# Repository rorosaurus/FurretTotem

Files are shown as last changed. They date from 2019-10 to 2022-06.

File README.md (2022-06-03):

## Wait but how?
* The LED panels are driven by an ESP32, controlled by a phone via Wifi!
* Yes, he's built using "Arduino"! No, they aren't normal "Neopixel" LEDs, they're HUB75!  Yes, he is adorable!
* The LED panels were $25 each and the microcontroller was $5. It's powered by a normal USB battery pack!
* The original pixel art animation was done by the extremely talented [Alex Illustration](https://www.artstation.com/alexillustration)! We used Photoshop to modify the original animation and to make all the other animations!

## Where is Furret?
Furret uses [Meshtastic](https://meshtastic.org/), a peer-to-peer LoRa mesh network, for long range (up to 10km!) reliable texting and GPS coordinate sharing! After getting your hardware (~$30) and setting up the device, join his channel and you can find Furret easily at festivals! We'll try to announce future planned events on Instagram!

[Click here to join his channel](https://www.meshtastic.org/d/#CjAYAyIgmvE-KciSpfpBhmnGTf2xxqEcX0OudQ_G3KwMii1EzjIqClJhdmVGdXJyZXQ), or scan the QR code below!

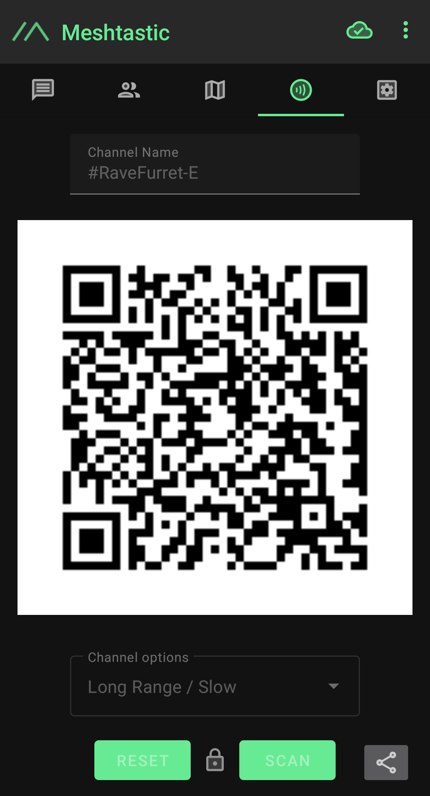
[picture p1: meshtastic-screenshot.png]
Furret's Meshtastic Channel


## Special Thanks
* [@alex_illustrat](https://twitter.com/alex_illustrat) - who [originally created the 8bit pixel art for Furret Walking](https://www.youtube.com/watch?v=ylnLUMmBNKc). See more of his work on [ArtStation](https://alexillustration.artstation.com/)!
* [narpy](https://www.youtube.com/channel/UCKYFHftFxQOJghmrEaK32sg) - for [starting the most adorable, wholesome, meme](https://www.youtube.com/watch?v=JVHybsJbTFY)
* [@pikachutotem](https://www.instagram.com/pikachutotem/) - who inspired me to make Furret!
* Sprite_tm, Craig A. Lindley, Louis Beaudoin, and Marc Merlin - for the below libraries and helpful forum posts :)
* [bigclive](https://www.youtube.com/channel/UCtM5z2gkrGRuWd0JQMx76qA) for showing me the [perfect bubble blowing mechanism](https://www.youtube.com/watch?v=BvQtl3ciGcA)!

## Code
This repository isn't meant to be a good sample project, it's just my personal project. It was built on top of so many incredible libraries:
* [Arduino core for the ESP32](https://github.com/espressif/arduino-esp32)
* [SmartMatrix Library for ESP32](https://github.com/pixelmatix/SmartMatrix/tree/teensylc)
  * I did a [dirty hack](https://github.com/rorosaurus/SmartMatrix/commit/c46fe8d7be686caaaa3b7198bc4b7b24c6114df8) to free up some DMA memory to enable Wifi for this project.
* [Animated GIFs on ESP32](https://github.com/marcmerlin/AnimatedGIFs)
* [Arduino plugin for uploading files to ESP32 file system](https://github.com/me-no-dev/arduino-esp32fs-plugin)

## Hardware
* [PCB I designed](https://github.com/rorosaurus/esp32-hub75-driver) to drive HUB75 panels with an ESP32: [Buy on Tindie!](https://www.tindie.com/products/18357/)
  * This part is optional, but *greatly* simplifies your wiring!
* ESP32-DEVKIT-V1: [Amazon ($14 for 2)](https://smile.amazon.com/gp/product/B07Q576VWZ/)
  * You can use a different ESP32 if you don't use my PCB. Just remember to verify it has the required pins mentioned below!
* 128x64px, P2.5, 1/32, HUB75E purchased on [AliExpress](https://www.aliexpress.com/item/32972741517.html?spm=a2g0s.12269583.0.0.48e74198VArDtK)
* Bubble machine extracted from children's bubble wand toy, purchased on [eBay](https://www.ebay.com/itm/332880742452)
* Some PVC pipe and a tripod!
* Furret's powered by a 100Wh USB battery bank! At full brightness, one panel can pull about 2 Amps @ 5 Volts. Since the LED panel power requirements can spike depending on the animation, I recommend running the ESP32 from a separate 5V power source to avoid brownouts due to voltage sag.

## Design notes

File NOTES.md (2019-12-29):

## Power Notes

Powering both panels off one 5V/3A USB port, I can reach about 150/255 before nearing 3A. Some animations with more white pixels would breach 3A and significantly reduce voltage (below 4V).

It's best to power the ESP32 (~1.5W constant) separately, so that voltage sag from the panels does not cause brownouts.

For sunlight conditions, the ability to go brighter would be better.  Maybe use 2 ports and split up the power distribution for each panel?

**Actual power measurements:**
* ESP32 running basic-walk.gif: `1W`
* ESP32 with Wifi ON running basic-walk.gif: `1.5W`
* Bubble machine running @ 5V: `1.5-4W`
* 1x LED panel running basic-walk.gif:

Brightness | Power
-----------|------
10/255 | ~1.5W
25/255 | ~2W
50/255 | 3W
128/255 | 5.7W
165/255 | 6.8W
200/255 | 8.3W
255/255 | 10W

## Checking DMA-capable memory free
````
Serial.print("8-bit/DMA Memory Available: ");
Serial.println(heap_caps_get_free_size(MALLOC_CAP_DMA));
````

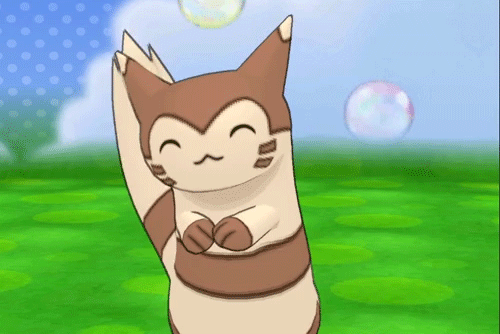
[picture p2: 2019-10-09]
head-bob-loop.gif

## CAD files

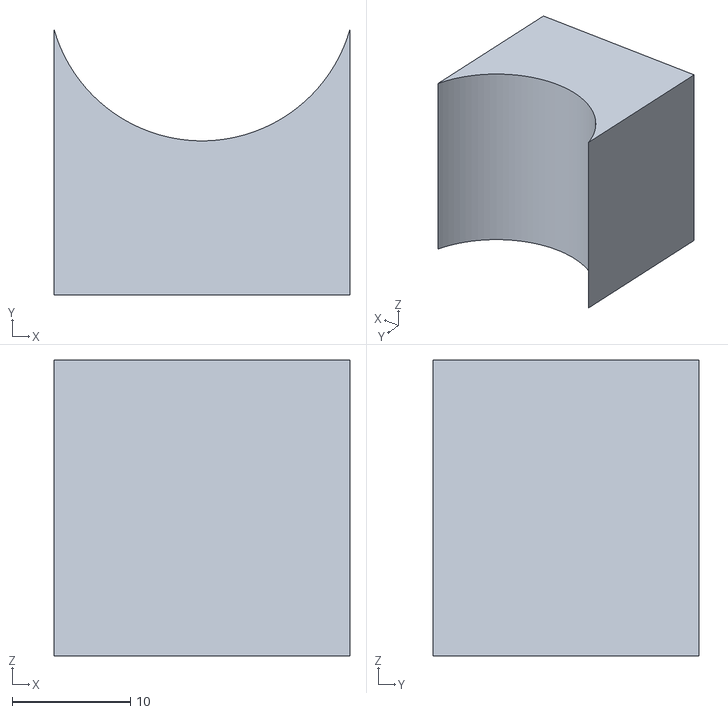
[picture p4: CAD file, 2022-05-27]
hardware/prisim-light/light-mount v0.stl
25.0 x 22.4 x 25.0

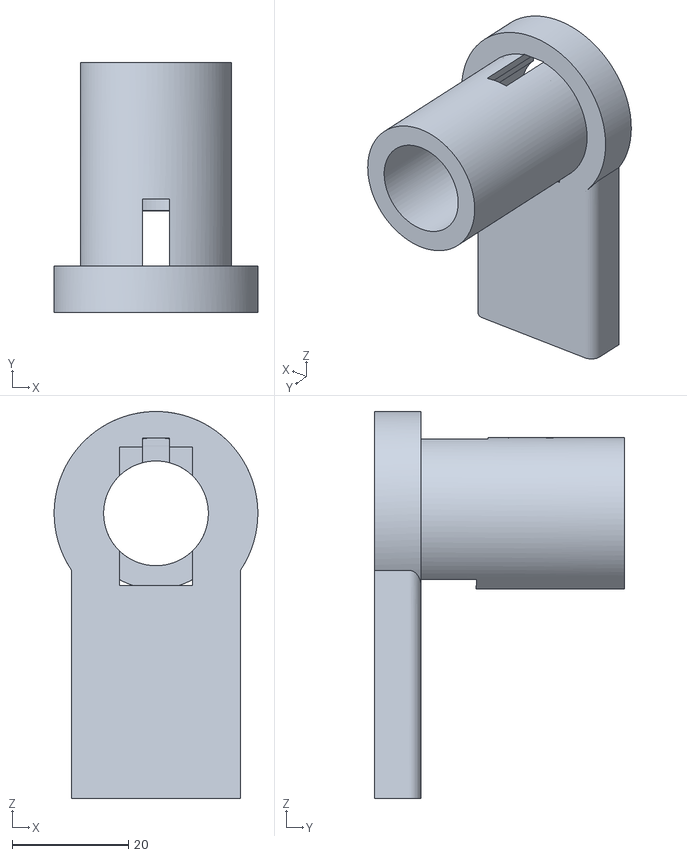
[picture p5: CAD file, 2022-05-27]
hardware/prisim-light/FS90R-mount v16.stl
35.0 x 43.0 x 66.5

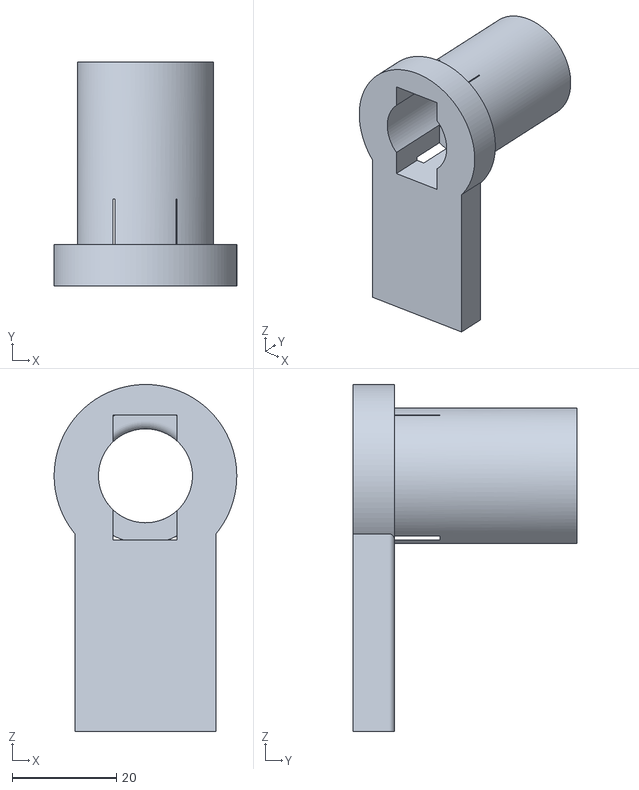
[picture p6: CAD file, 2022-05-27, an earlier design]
hardware/prisim-light/FS90R-mount v6.stl
35.0 x 43.0 x 66.5

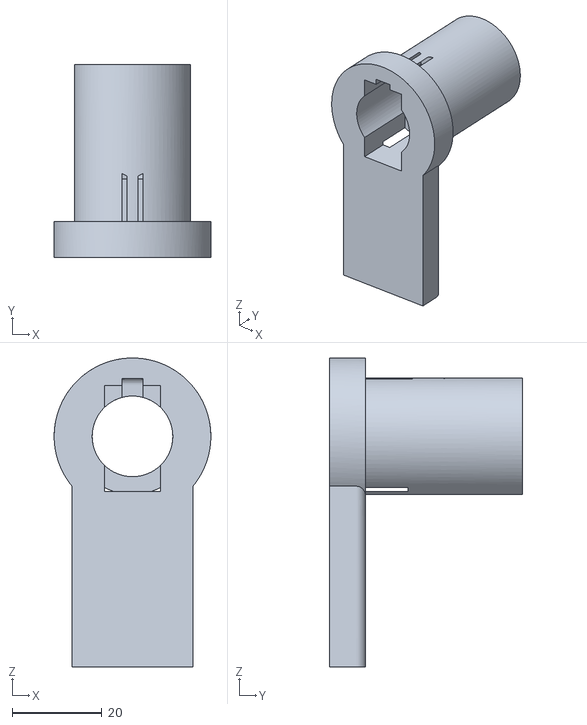
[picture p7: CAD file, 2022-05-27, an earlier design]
hardware/prisim-light/FS90R-mount v14.stl
35.0 x 43.0 x 69.0

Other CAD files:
hardware/prisim-light/FS90R-mount v15.stl
hardware/prisim-light/FS90R-mount v3.stl
hardware/prisim-light/FS90R-mount v9.stl
hardware/prisim-light/FS90R-mount v10.stl
hardware/prisim-light/FS90R.f3d

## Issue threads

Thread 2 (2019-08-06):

consider FatFS instead of SPIFFS

marcmerlin, 2019-08-06:
As you add more data to SPIFFS, you'll notice that the reads slowdown to a point that your animation is not nice anymore.
Fix for this is switching to FatFS:
http://marc.merlins.org/perso/arduino/post_2019-03-30_Using-FatFS-FFat-on-ESP32-Flash-With-Arduino.html

rorosaurus, 2019-10-01:
Thanks Marc!  I will definitely plan on migrating to that as I expand this project! :)

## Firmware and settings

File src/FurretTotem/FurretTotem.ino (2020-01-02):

/*
 * HE WALK!
 */

#define DISABLE_MATRIX_TEST
#define NEOMATRIX

#define defaultBrightness 50 // 25 is good for home testing, 50 is a good default for shows
#define minBrightness 0
#define maxBrightness 150 // 165 is roughly equivalent to 3A with 2 displays, but leave some headroom

#include <DNSServer.h>
#include <WiFi.h>
#include <AsyncTCP.h>
#include "ESPAsyncWebServer.h"
#include "secrets.h"
#include "GifAnim_Impl.h"

int currentBrightness = defaultBrightness;
bool nextFlag = false;
bool prevFlag = false;
int newIndex = -1;
int currentIndex = FIRSTINDEX;

// If the matrix is a different size than the GIFs, allow panning through the GIF
int OFFSETX = 0;
int OFFSETY = 0;
int FACTX = 0;
int FACTY = 0;

int num_files;
String filenameOptions = "";

//DNSServer dnsServer;
AsyncWebServer server(80);

String processor(const String& var){
  if(var == "MIN_BRIGHTNESS") return String(minBrightness);
  if(var == "MAX_BRIGHTNESS") return String(maxBrightness);
  if(var == "CURRENT_BRIGHTNESS") return String(currentBrightness);
  if(var == "CURRENT_INDEX") return String(currentIndex);
  if(var == "LIST_FILENAME_OPTIONS") return filenameOptions;
  return String();
}

class CaptiveRequestHandler : public AsyncWebHandler {
public:
  CaptiveRequestHandler() {}
  virtual ~CaptiveRequestHandler() {}

  bool canHandle(AsyncWebServerRequest *request){
    //request->addInterestingHeader("ANY");
    return true;
  }

  void handleRequest(AsyncWebServerRequest *request) {
    // handle other file requests
    if (request->url() == "/styles.css"){
      request->send(SPIFFS, "/www/styles.css", "text/css");
    }
    else { // handle parameters
      if(request->hasParam("next")){
        Serial.println("NEXT pressed");
        nextFlag = true;
      }
      if(request->hasParam("prev")){
        Serial.println("PREVIOUS pressed");
        prevFlag = true;
      }
      if(request->hasParam("brightness")){
        AsyncWebParameter* p = request->getParam("brightness");
        currentBrightness = p->value().toInt();
        Serial.print("New brightness: ");
        Serial.println(currentBrightness);
      }
      if(request->hasParam("newFileIndex")){
        AsyncWebParameter* p = request->getParam("newFileIndex");
        newIndex = p->value().toInt();
        Serial.print("New file index: ");
        Serial.println(newIndex);
      }

      // catch everything else
      //Send index.htm with template processor function
      request->send(SPIFFS, "/www/index.htm", "text/html", false, processor);
    }
  }
};

// Setup method runs once, when the sketch starts
void setup() {
    Serial.begin(115200);
    
    Serial.println("Starting AnimatedGIFs Sketch");
    sav_setup();

    #if ENABLE_SCROLLING == 1
	  matrix.addLayer(&scrollingLayer); 
    #endif

    // Determine how many animated GIF files exist
    num_files = enumerateGIFFiles(GIF_DIRECTORY, true);

    if(num_files < 0) {
      #if ENABLE_SCROLLING == 1
      scrollingLayer.start("No gifs directory", -1);
      #endif
      die("No gifs directory");
    }

    if(!num_files) {
        #if ENABLE_SCROLLING == 1
        scrollingLayer.start("Empty gifs directory", -1);
        #endif
        die("Empty gifs directory");
    }
    
    Serial.print("Index of files: 0 to ");
    Serial.println(num_files);
    Serial.flush();
    
    // We didn't have enough DMA memory to use Wifi until I made this hack in SmartMatrix, effectively removing the double buffer:
    // https://github.com/rorosaurus/SmartMatrix/commit/c46fe8d7be686caaaa3b7198bc4b7b24c6114df8
    Serial.println("Configuring access point...");
    WiFi.softAP(ssid, password, 1, 1, 1); // channel 1 (default), hide SSID, max connected clients = 1
    
//    dnsServer.start(53, "*", WiFi.softAPIP());
    
    server.addHandler(new CaptiveRequestHandler());//only when requested from AP
    server.begin();
    Serial.print("Server started. IP Address: ");
    Serial.println(WiFi.softAPIP());
}

void adjust_gamma(float change) {
#ifdef NEOMATRIX
    matrix_gamma += change;
    matrix->precal_gamma(matrix_gamma);
    Serial.print("Change gamma to: "); 
    Serial.println(matrix_gamma); 
#else
    Serial.println("Gamma changing not supported in SmartMatrix lib"); 
#endif
}


void loop() {
//    dnsServer.processNextRequest();

    matrixLayer.setBrightness(currentBrightness);
    
    static unsigned long lastTime = millis();
    static int index = FIRSTINDEX;
    currentIndex = index;
    static int8_t new_file = 1;
    static uint16_t frame = 0;
    // allow stalling on a picture if requested
    static uint32_t longer = 0;
    char readchar;
    // frame by frame display
    static bool debugframe = false;
    bool gotnf = false;
    // clear display before each frame
    static bool clear = false;

  if (nextFlag){
    Serial.println("Wifi => next");
    new_file = 1;  
    index++;
    nextFlag = false;
  }
  
  if (prevFlag){
    Serial.println("Wifi => previous");
    new_file = 1;  
    index--;
    prevFlag = false;
  }
  if (newIndex != -1){
      new_file = 1;
      index = newIndex;
      newIndex = -1;
  }

    if (Serial.available()) readchar = Serial.read(); else readchar = 0;

    switch(readchar) {
    case 'n': 
	Serial.println("Serial => next"); 
	new_file = 1;  
	index++;
	break;

    case 'p':
	Serial.println("Serial => previous");
	new_file = 1;
	index--;
	break;

    case 'f':
	Serial.println("Serial => debug frames, press 'g' for next frame");
	debugframe = true;
	longer = 3600; //  if frame debugging, keep current gif for 1h
	break;

    case 'g':
	Serial.println("Serial => next frame");
	gotnf = true;
	break;

    case 'c':
	Serial.print("Toggle clear screen: ");
	clear = !clear;;
	Serial.println(clear);
	break;

    case '+': adjust_gamma(+0.05); break;

    case '-': adjust_gamma(-0.05); break;

    default:
	// BUG: this does not work for index '0', just type '1', and 'p'
	if (readchar) {
	    while ((readchar >= '0') && (readchar <= '9')) {
		new_file = 10 * new_file + (readchar - '0');
		readchar = 0;
		if (Serial.available()) readchar = Serial.read();
	    }

	    if (new_file) {
		Serial.print("Got new file via serial ");
		Serial.println(new_file);
		index = new_file;
	    } else {
		Serial.print("Got serial char ");
		Serial.println(readchar);
	    }
	}
    }

    if (debugframe) {
	if (! gotnf) return;
    }

  if (new_file) { 
	frame = 0;
	new_file = 0;
	lastTime = millis();
	if (index >= num_files) index = 0;
	if (index <= -1) index = num_files - 1;
        Serial.print("Fetching file index #");
        Serial.println(index);

        if (openGifFilenameByIndex(GIF_DIRECTORY, index) >= 0) {
            // Can clear screen for new animation here, but this might cause flicker with short animations
	    // matrix->clear();

            decoder.startDecoding();
        } else {
	    die("FATAL: failed to open file");
	}
    }

    if (clear) screenClearCallback();

    // decode the gif
    decoder.decodeFrame();
    frame++;
    if (debugframe) {
	Serial.print("Displayed frame #");
	Serial.print(frame);
	Serial.println(". Press g for next frame");
    }
#if DEBUGLINE
    delay(1000000);
#endif
}

// vim:sts=4:sw=4

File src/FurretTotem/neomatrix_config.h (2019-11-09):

#ifndef neomatrix_config_h
#define neomatrix_config_h

bool init_done = 0;
#define ARRAY_SIZE(A) (sizeof(A) / sizeof((A)[0]))

// No SmartMatrix on ESP8266, but otherwise default to SmartMatrix
// unless NEOPIXEL_MATRIX is defined before including this.
#ifdef ESP8266
//#define SSD1331
//#define SSD1331_ROTATE 1
#define M32B8X3
//#define M16BY16T4
#define NEOPIXEL_MATRIX
#endif

// Teensy 3.6
#ifdef __MK66FX1M0__
#define ILI9341
#define ILI_ROTATE 1
#define NEOPIXEL_MATRIX
#endif

#ifndef NEOPIXEL_MATRIX
#define SMARTMATRIX
#endif

#include <Adafruit_GFX.h>

//============================================================================ 
// Matrix defines (SMARTMATRIX vs NEOMATRIX and size)
//============================================================================ 

// The ESP32 FastLED defines below must be defined before FastLED.h is loaded
#ifndef SMARTMATRIX
    #ifdef ESP32
        #ifdef ESP32_16PINS
            // This uses https://github.com/hpwit/fastled-esp32-16PINS.git
            // instead of https://github.com/samguyer/FastLED.git
            #define FASTLED_ALLOW_INTERRUPTS 0
            #define FASTLED_SHOW_CORE 0
        #else
            // Allow infrared
            #define FASTLED_ALLOW_INTERRUPTS 1
            #pragma message "Please use https://github.com/samguyer/FastLED.git if stock FastLED is unstable with ESP32"
        #endif // ESP32_16PINS
    #endif

    #if !defined(M16BY16T4)
        #ifdef ESP32
            // 64x64 matrix with optional 16 pin parallel driver
            #define M64BY64
            // 55fps without 16PINS, 110fps with 16PINS
            //#define ESP32_16PINS
        #elif ESP8266
            // ESP8266 shirt with neopixel strips
            #define M32B8X3
        #endif
    #endif
    
    #include <FastLED_NeoMatrix.h>
    #pragma message "Compiling for NEOMATRIX"
#else
    // CHANGEME, see MatrixHardware_ESP32_V0.h in SmartMatrix/src
    #define GPIOPINOUT ESP32_FORUM_PINOUT
    #pragma message "Compiling for SMARTMATRIX with NEOMATRIX API"
    //#include <SmartLEDShieldV4.h>  // if you're using SmartLED Shield V4 hardware
    #include <SmartMatrix3.h>
    #include <SmartMatrix_GFX.h>
#endif // SMARTMATRIX

#include <FastLED.h>

#ifdef LEDMATRIX
// Please use https://github.com/marcmerlin/LEDMatrix/tree/ledmalloc for
// zero copy/no malloc code to work.
#include <LEDMatrix.h>
#endif

#if defined(SMARTMATRIX)
uint8_t matrix_brightness = 25;

#ifdef ESP32
#pragma message "Compiling for ESP32 with 128x64 32 scan panel"
const uint8_t kPanelType = SMARTMATRIX_HUB75_64ROW_MOD32SCAN;   // use SMARTMATRIX_HUB75_16ROW_MOD8SCAN for common 16x32 panels
const uint16_t MATRIX_TILE_WIDTH = 128; // width of EACH NEOPIXEL MATRIX (not total display)
const uint16_t MATRIX_TILE_HEIGHT= 64; // height of each matrix
#elif defined(__MK66FX1M0__) // my teensy 3.6 is connected to a 64x64 panel
#pragma message "Compiling for Teensy with 64x64 32 scan panel"
//const uint8_t kPanelType = SMARTMATRIX_HUB75_32ROW_MOD16SCAN;   // use SMARTMATRIX_HUB75_16ROW_MOD8SCAN for common 16x32 panels
const uint8_t kPanelType = SMARTMATRIX_HUB75_64ROW_MOD32SCAN;
const uint16_t MATRIX_TILE_WIDTH = 64; // width of EACH NEOPIXEL MATRIX (not total display)
const uint16_t MATRIX_TILE_HEIGHT= 64; // height of each matrix
#else
#error Unknown architecture (not ESP32 or teensy 3.5/6)
#endif
// Used by LEDMatrix
const uint8_t MATRIX_TILE_H     = 1;  // number of matrices arranged horizontally
const uint8_t MATRIX_TILE_V     = 1;  // number of matrices arranged vertically

// Used by NeoMatrix
const uint16_t mw = MATRIX_TILE_WIDTH *  MATRIX_TILE_H;
const uint16_t mh = MATRIX_TILE_HEIGHT * MATRIX_TILE_V;
const uint32_t NUMMATRIX = mw*mh;

// Compat for some other demos
const uint32_t NUM_LEDS = NUMMATRIX; 
const uint16_t MATRIX_HEIGHT = mh;
const uint16_t MATRIX_WIDTH = mw;

/// SmartMatrix Defines
#define COLOR_DEPTH 24         // known working: 24, 48 - If the sketch uses type `rgb24` directly, COLOR_DEPTH must be 24
const uint8_t kMatrixWidth = mw;
const uint8_t kMatrixHeight = mh;
const uint8_t kRefreshDepth = 24;       // known working: 24, 36, 48
const uint8_t kDmaBufferRows = 0;       // known working: 2-4, use 2 to save memory, more to keep from dropping frames and automatically lowering refresh rate
const uint8_t kMatrixOptions = (SMARTMATRIX_OPTIONS_NONE);      // see http://docs.pixelmatix.com/SmartMatrix for options
const uint8_t kBackgroundLayerOptions = (SM_BACKGROUND_OPTIONS_NONE);

SMARTMATRIX_ALLOCATE_BUFFERS(matrixLayer, kMatrixWidth, kMatrixHeight, kRefreshDepth, kDmaBufferRows, kPanelType, kMatrixOptions);
SMARTMATRIX_ALLOCATE_BACKGROUND_LAYER(backgroundLayer, kMatrixWidth, kMatrixHeight, COLOR_DEPTH, kBackgroundLayerOptions);

#ifdef LEDMATRIX
// cLEDMatrix defines 
cLEDMatrix<MATRIX_TILE_WIDTH, -MATRIX_TILE_HEIGHT, HORIZONTAL_MATRIX,
    MATRIX_TILE_H, MATRIX_TILE_V, HORIZONTAL_BLOCKS> ledmatrix(false);
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

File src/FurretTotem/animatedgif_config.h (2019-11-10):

#ifndef animatedgif_config
#define animatedgif_config

// control if we decode in 32x32 or 64x64, or something else
#ifdef ESP8266
#define gif_size 32
#else
#define gif_size 64
#endif

/* GifDecoder needs lzwMaxBits
 * The lzwMaxBits value of 12 supports all GIFs, but uses 16kB RAM
 * lzwMaxBits can be set to 10 or 11 for small displays, 12 for large displays
 * All 32x32-pixel GIFs tested work with 11, most work with 10
 */
const int lzwMaxBits = 12;

//#define NEOMATRIX // Switch to NEOMATRIX backend from native SMARTMATRIX backend
//#define NEOPIXEL_MATRIX  // If NEOMATRIX, use FastLED::NeoMatrix, not SmartMatrix_GFX

// if you want to display a file and display that one first
#define FIRSTINDEX 0
//#define DEBUGLINE 16

// Use Neomatrix API (which in turn could be using SmartMatrix driver)?
// This is defined in main ino that calls sav_loop
#ifdef NEOMATRIX
    // This doesn't work due to variables being redefined. Sigh...
    // instead it's included once from AnimatedGIFs.ino
    //#include "neomatrix_config.h"
#else // NEOMATRIX
    #pragma message "Compiling for Native SmartMatrix"
    // CHANGEME, see MatrixHardware_ESP32_V0.h in SmartMatrix/src
    #define GPIOPINOUT 3
    #define ENABLE_SCROLLING  1
    #if defined (ARDUINO)
        //#include <SmartLEDShieldV4.h>  // uncomment this line for SmartLED Shield V4 (needs to be before #include <SmartMatrix3.h>)
        #include <SmartMatrix3.h>
    #elif defined (SPARK)
        #include "application.h"
        #include "SmartMatrix3_Photon_Apa102/SmartMatrix3_Photon_Apa102.h"
    #endif

    // Neomatrix brightness is different (full brightness can use up 40A) and defined
    // to a different value in neomatrix_config.h
    // range 0-255
    const int defaultBrightness = 255;
    const uint8_t kMatrixWidth = gif_size;        // known working: 32, 64, 96, 128
    const uint8_t kMatrixHeight = gif_size;       // known working: 16, 32, 48, 64
    /* SmartMatrix configuration and memory allocation */
    #define COLOR_DEPTH 24                  // known working: 24, 48 - If the sketch uses type `rgb24` directly, COLOR_DEPTH must be 24
    const uint8_t kRefreshDepth = 24;       // known working: 24, 36, 48
    const uint8_t kDmaBufferRows = 2;       // known working: 2-4
    const uint8_t kPanelType = SMARTMATRIX_HUB75_32ROW_MOD16SCAN; // use SMARTMATRIX_HUB75_16ROW_MOD8SCAN for common 16x32 panels
    //const uint8_t kPanelType = SMARTMATRIX_HUB75_64ROW_MOD32SCAN;
    const uint8_t kMatrixOptions = (SMARTMATRIX_OPTIONS_NONE);    // see http://docs.pixelmatix.com/SmartMatrix for options
    const uint8_t kBackgroundLayerOptions = (SM_BACKGROUND_OPTIONS_NONE);
    const uint8_t kScrollingLayerOptions = (SM_SCROLLING_OPTIONS_NONE);
#endif

// If the matrix is a different size than the GIFs, set the offset for the upper left corner
// (negative or positive is ok).
extern int OFFSETX;
extern int OFFSETY;
extern int FACTX;
extern int FACTY;

// Note, you can use an sdcard on ESP32 or ESP8266 if you really want,
// but if your data fits in built in flash, why not use it?
// Use built in flash via SPIFFS/FATFS
// esp8266com/esp8266/libraries/SD/src/File.cpp
// ESP8266: http://esp8266.github.io/Arduino/versions/2.3.0/doc/filesystem.html#uploading-files-to-file-system
// ESP32: https://github.com/me-no-dev/arduino-esp32fs-plugin
// https://github.com/marcmerlin/esp32_fatfsimage/blob/master/README.md
#if defined(ESP8266)
    #include <FS.h>
    #define FSO SPIFFS
    #if gif_size == 64
        #define GIF_DIRECTORY "/gifs64/"
    #else
        #define GIF_DIRECTORY "/gifs/"
    #endif
    extern "C" {
        #include "user_interface.h"
    }
#elif defined(ESP32)
    #include <SPIFFS.h>
    #define FSO SPIFFS
    //#include "FFat.h"
    //#define FSO FFat
    //#define FSOFAT
    // Do NOT add a trailing slash, or things will fail
    #define GIF_DIRECTORY "/gifs"
#else
    #define FSO SD
    #define FSOSD
    #if defined (ARDUINO)
    #include <SD.h>
    #elif defined (SPARK)
    #include "sd-card-library-photon-compat/sd-card-library-photon-compat.h"
    #endif
    // Chip select for SD card on the SmartMatrix Shield or Photon
    // Teensy 3.5/3.6
    #if defined(__MK64FX512__) || defined(__MK66FX1M0__)
        #define SD_CS BUILTIN_SDCARD
    #elif defined(ESP32)
        #define SD_CS 5
    #elif defined (ARDUINO)
        #define SD_CS 15
        //#define SD_CS BUILTIN_SDCARD
    #elif defined (SPARK)
        #define SD_CS SS
    #endif
    
    #if defined(ESP32)
        // ESP32 SD Library can't handle a trailing slash in the directory name
        #if gif_size == 64
            #define GIF_DIRECTORY "/gifs64"
        #else
            #define GIF_DIRECTORY "/gifs"
        #endif
    #else
        // Teensy SD Library requires a trailing slash in the directory name
        #if gif_size == 64
            #define GIF_DIRECTORY "/gifs64/"
        #else
            #define GIF_DIRECTORY "/gifs/"
        #endif
    #endif
#endif
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

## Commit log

2018-07-11 Added ESP32 SPIFFS support (still somewhat crashing, but close).
    [FilenameFunctions.cpp, neomatrix_config.h]
2018-07-11 Added warning for ESP32
2018-07-12 Minimal example of how to animate a GIF read from SPIFFS on ESP32/ESP8266.
2018-07-13 Shortened the code a bit.
    [SimpleGifAnimViewer.ino]
2018-08-15 Added dual driver ESP32 support.
2019-01-08 Fixes for NEOMATRIX implementation
    - re-ran as NeoMatrix/M16BY16T4 by default
    - neomatrix doesn't have custom matrix_clear and matrix_show anymore
    - re-org'ed neomatrix_config a lot
    TESTED=M16BY16T4
    [neomatrix_config.h]
2019-01-20 Fixed SmartMatrix::GFX backend support.
    [neomatrix_config.h]
2019-02-27 Flush teensy serial before asking for input.
    Other minor updates to matrix init, including using gamma on
    SmartMatrix.
2019-02-27 Refactored/fixed Native SmartMatrix support.
    - SmartMatrix init vars moved to config.h
    - Removed analogread that breaks SmartMatrix output on ESP32
    - Switched back to Native SmartMatrix instead of SmartMatrix through
    SmartMatrix::GFX (#define NEOMATRIX)
    - Added pragma messages to give a clue which code path we're using
    - Slirp out serial output on teensy to avoid looping it back in serial
    read calls
    - Imported/sync LEDMATRIX init demo code (not used in AnimatedGifs)
    [neomatrix_config.h]
2019-03-04 size.h cleanup, get SimpleGifAnimViewer to work again
    OFFSETxy is now an extern defined in the main file (remove size.h)
    Fix SimpleGifAnimViewer to be compatible with Neomatrix and SmartMatrix
    [SimpleGifAnimViewer.ino]
2019-03-05 Fixed compilation issues for SimpleGifAnimViewer.
    [SimpleGifAnimViewer.ino]
2019-03-07 Big rework so that the implementation can be included in other code.
    GifAnim_Impl.h does all the work now.
    lzwMaxBits moved to config.h since it is a config option
    SimpleGifAnimViewer is now SimpleGifAnimViewer2 (v1 will be simpler
    even)
    [GifDecoder_Impl.h, SimpleGifAnimViewer.ino, neomatrix_config.h]
2019-03-09 Switch GifDecoder to using malloc in case it helps ESP32.
2019-03-10 Switch more vars from arrays to malloc.
    But imageData and imageDataBU do not work when malloc'ed (I get
    a screen with garbage colors).
    [GifDecoder_Impl.h]
2019-03-10 Convert imageData imageDataBU to malloc (fix for sizeof not working anymore)
    [GifDecoder_Impl.h]
2019-03-10 Turn off ESP32 memory debugging.
2019-03-28 Show memory left if malloc fails.
    [GifDecoder_Impl.h]
2019-03-29 Added frame by frame single stepping.
    Also added option to clear the screen between each frame.
2019-03-31 Fixed sizeof bug for tempbuffer.
    [GifDecoder_Impl.h]
2019-03-31 Teensy fixes.
2019-04-24 Fixed ESP8266 SPIFFS support.
    Sadly the API is different from all other FS implementations :(
    [FilenameFunctions.cpp]
2019-05-03 New file for new size of 3008KB due to esp32-arduino partition change.
2019-05-03 Updated partition change due to esp32-arduino upstream change.
2019-05-09 Fixed ESP8266 support and better documented NeoMatrix usage.
    [animatedgif_config.h]
2019-05-11 Fixed decoding bug on non square arrays.
    matrix_size is now gif_size to avoid such problems.
    [animatedgif_config.h, neomatrix_config.h]
2019-06-27 switch to SPIFFS and increase loop time
2019-07-24 disable timer to change animation
2019-07-24 skip over index 0, reserving for bubbles animation
    [FurretTotem.ino, animatedgif_config.h]
2019-08-07 drop enough frames to prevent memory reallocation
2019-08-20 prepping for burning man bike
    [FurretTotem.ino, animatedgif_config.h, neomatrix_config.h]
2019-11-10 fix a bug in getGIFFilenameByIndex
    [FilenameFunctions.cpp, FurretTotem.ino, animatedgif_config.h]
2019-11-16 couple more glitches
2019-11-17 power notes and max brightness
2019-11-19 web remote now tracks current index for clarity
2019-11-20 fix iOS rounded buttons
2019-12-28 hack wifi buffer to save more DMA memory
2019-12-31 try to improve stability with an awful memory hack
    [FurretTotem.ino]
2022-05-27 update source
    [FS90R-mount v10.stl, FS90R-mount v14.stl, FS90R-mount v15.stl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]
